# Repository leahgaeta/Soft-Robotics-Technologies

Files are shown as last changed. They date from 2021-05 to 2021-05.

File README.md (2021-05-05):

# Soft Robotic Technologies
This repo includes everything needed to build a capacitive sensing sock with a laminar jamming stiffening mechanism to correct and stabilize ankle movement, as well as videos created for my Soft Robotic Technologies course taught by [Professor Tommaso Ranzani](https://www.bu.edu/eng/profile/tommaso-ranzini-phd/) at Boston University (ME 568).

### A Capacitive-Sensing Sock with Laminar Jamming Stiffening to Correct & Stabilize Over-Plantar Flexion at the Ankle
**Materials for Fabrication & Testing:**
- [Capacitive-sensing sock](https://github.com/leahgaeta/Soft-Robotics-Technologies/raw/main/CapSenseSock.pdf)
  - [Mold .stl file](https://github.com/leahgaeta/Soft-Robotics-Technologies/blob/main/CapSenseMold.stl) - recommend preheating the build plate to improve adhesion and prevent thermal warping; also recommend print settings of 160 microns layer height, 40 mm/s print speed, 15% cubic infill.
  - [Mold drawing](https://github.com/leahgaeta/Soft-Robotics-Technologies/raw/main/CapSensorDrawing.pdf) - for overall dimensions if fabricating the mold without a 3D printer.
- [Laminar jamming mechanism](https://github.com/leahgaeta/Soft-Robotics-Technologies/raw/main/LJ_Materials.pdf)

**Procedure:**
- [Capacitive sensor fabrication](https://github.com/leahgaeta/Soft-Robotics-Technologies/raw/main/CapSensorFabrication.pdf)
- [Capacitive sensor with the sock]()
- [Laminar jamming structure]()
- [Arduino hook-up]()
- [Arduino code](https://github.com/leahgaeta/Soft-Robotics-Technologies/blob/main/ME568_Final_Project.ino)
- [Measuring ankle plantar flexion](https://github.com/leahgaeta/Soft-Robotics-Technologies/raw/main/AngleMeasure.pdf)
- [Validation of functionality]()

**Videos:**
- [Preliminary testing of the vacuum pump with the microcontroller in response to capacitance](https://www.youtube.com/watch?v=6RODMb19xsY&list=PLcbK43wpe5npEgS4IPYMW3b8mG1NXDAUV&index=7)
- [Example of prototype testing](https://www.youtube.com/watch?v=m9hGfniaSMc&list=PLcbK43wpe5npEgS4IPYMW3b8mG1NXDAUV&index=8)

### Other Explored Soft Robotic Technologies
- [SDM Finger Cable-Actuation](https://www.youtube.com/watch?v=M-p_GvDbpxU&list=PLcbK43wpe5npEgS4IPYMW3b8mG1NXDAUV&index=1)
- [Fluidic Actuators](https://www.youtube.com/watch?v=uoCWdHJRbhE&list=PLcbK43wpe5npEgS4IPYMW3b8mG1NXDAUV&index=2)
- [TPE Balloon Actuator](https://www.youtube.com/watch?v=CA4r7Kx_r18&list=PLcbK43wpe5npEgS4IPYMW3b8mG1NXDAUV&index=3)
- [Shape-Memory Alloy Actuator](https://www.youtube.com/watch?v=QtGa-lT5LOc&list=PLcbK43wpe5npEgS4IPYMW3b8mG1NXDAUV&index=4)
- [Soft Sensing](https://www.youtube.com/watch?v=x_DoucdEBAE&list=PLcbK43wpe5npEgS4IPYMW3b8mG1NXDAUV&index=5)
- [Granular & Laminar Jamming](https://www.youtube.com/watch?v=GqvPBZalNiA&list=PLcbK43wpe5npEgS4IPYMW3b8mG1NXDAUV&index=6)

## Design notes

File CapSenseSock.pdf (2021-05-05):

## Capacitive-Sensing Sock Materials

Leah T. Gaeta
Boston University, Dept. of Mechanical Engineering
- EcoFlex 00-30 Parts A & B (https://www.amazon.com/Smooth-Ecoflex-00-50-Platinum-Silicone/dp/B00GJ80HIC)
- 1.75 mm PLA for mold printing; (https://www.hatchbox3d.com/collections/pla) if no access to a 3D printer, then cardboard, hot glue, and packaging tape will suce for making the mold
- Mixing utensils for mixing Parts A and B together (https://www.amazon.com/dp/B08GCJ9KYH?aaxitk=fbd0d167cb8958185a16a57649ce70a7&hsa_cr_id=3728124250601)
- Xacto Knife (https://www.amazon.com/X-ACTO-2-Knife-Safety-Cap/dp/B000V1QV7O?hvadid=167119535166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)
- Conductive knit fabric (https://www.adafruit.com/product/1167)
- Ruler (https://www.amazon.com/Officemate-Classic-Stainless-Measurements-66612/dp/B00IXLPO8G?s=industrial) or measuring tape
- Sewing needle & thread (https://www.amazon.com/Supplies-Accessories-Portable-Traveller-Emergency/dp/B07FD297GK)
- Cotton sock, unisex size (https://www.amazon.com/gp/product/B08KYCYWJ6/ref=ppx_yo_dt_b_asin_title_o03_s00?ie=UTF8&psc=1)
- Extra fabric (https://www.amazon.com/Canvas-Drop-Cloth-Size-Cotton/dp/B07TBHJJ62)
- Alligator clips (https://www.amazon.com/gp/product/B06XX25HFX/ref=ppx_yo_dt_b_asin_title_o01_s01?ie=UTF8&psc=1)
- Goniometer (https://www.amazon.com/gp/product/B07SJ54W63/ref=ppx_yo_dt_b_asin_title_o03_s00?ie=UTF8&psc=1)
- Arduino Uno, jumper wires, and USB connection to a computer (https://store.arduino.cc/usa/arduino-starter-kit)

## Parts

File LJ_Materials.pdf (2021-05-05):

## Laminar Jamming Materials

Leah T. Gaeta
Boston University, Dept. of Mechanical Engineering
- Printer paper (https://www.amazon.com/gp/product/B00006L38Q/ref=ppx_yo_dt_b_asin_title_o01_s01?ie=UTF8&psc=1)
- Scissors & ruler
- Stretchlon TPE (https://www.fibreglast.com/product/stretchlon-200-bagging-film-1678/Vacuum_Bagging_Films_Peel_Ply_Tapes)
- Iron & ironing board (https://www.amazon.com/dp/B082JG1SR6?aaxitk=7f2c8ed0a6aad44603be81251b5097b4&hsa_cr_id=6329978520001)
- Aluminum foil (https://www.amazon.com/Reynolds-Wrap-Aluminum-Foil-Square/dp/B00UNT0Y2M?rdc=1)
- 3/16 in. tubing (https://www.amazon.com/Silicon-CellarBrew-Silicone-Brewing-Winemaking/dp/B07TH8H1QP)
- Miniature pump (https://www.amazon.com/NW-5V-6VDC-Miniature-Vacuum-100KPa/dp/B078H8V563)
- Transistors (https://www.amazon.com/Pieces-TIP120-Power-Darlington-Transistors/dp/B00NAY1IBS) & diodes (diodes can be found at the Arduino link)
- Locktite Adhesive (https://www.amazon.com/Loctite-Plastic-Adhesive-1-Ounce-1360694/dp/B001F7E9VI)
- Extra fabric (https://www.amazon.com/Canvas-Drop-Cloth-Size-Cotton/dp/B07TBHJJ62)
- Arduino Uno, jumper wires, and USB connection to a computer (https://store.arduino.cc/usa/arduino-starter-kit)

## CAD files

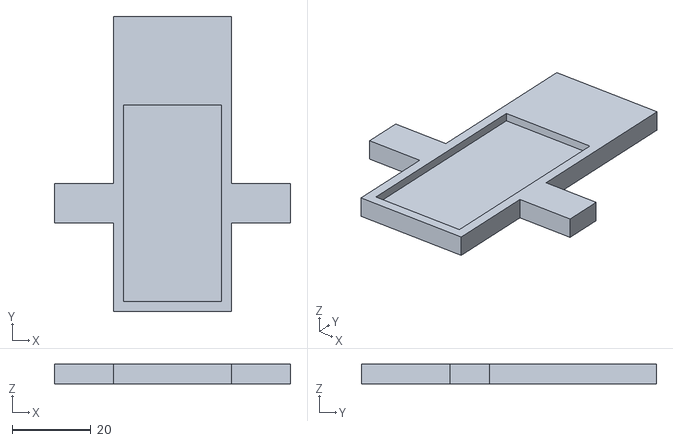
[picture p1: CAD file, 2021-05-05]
CapSenseMold.stl
60.0 x 75.0 x 5.00

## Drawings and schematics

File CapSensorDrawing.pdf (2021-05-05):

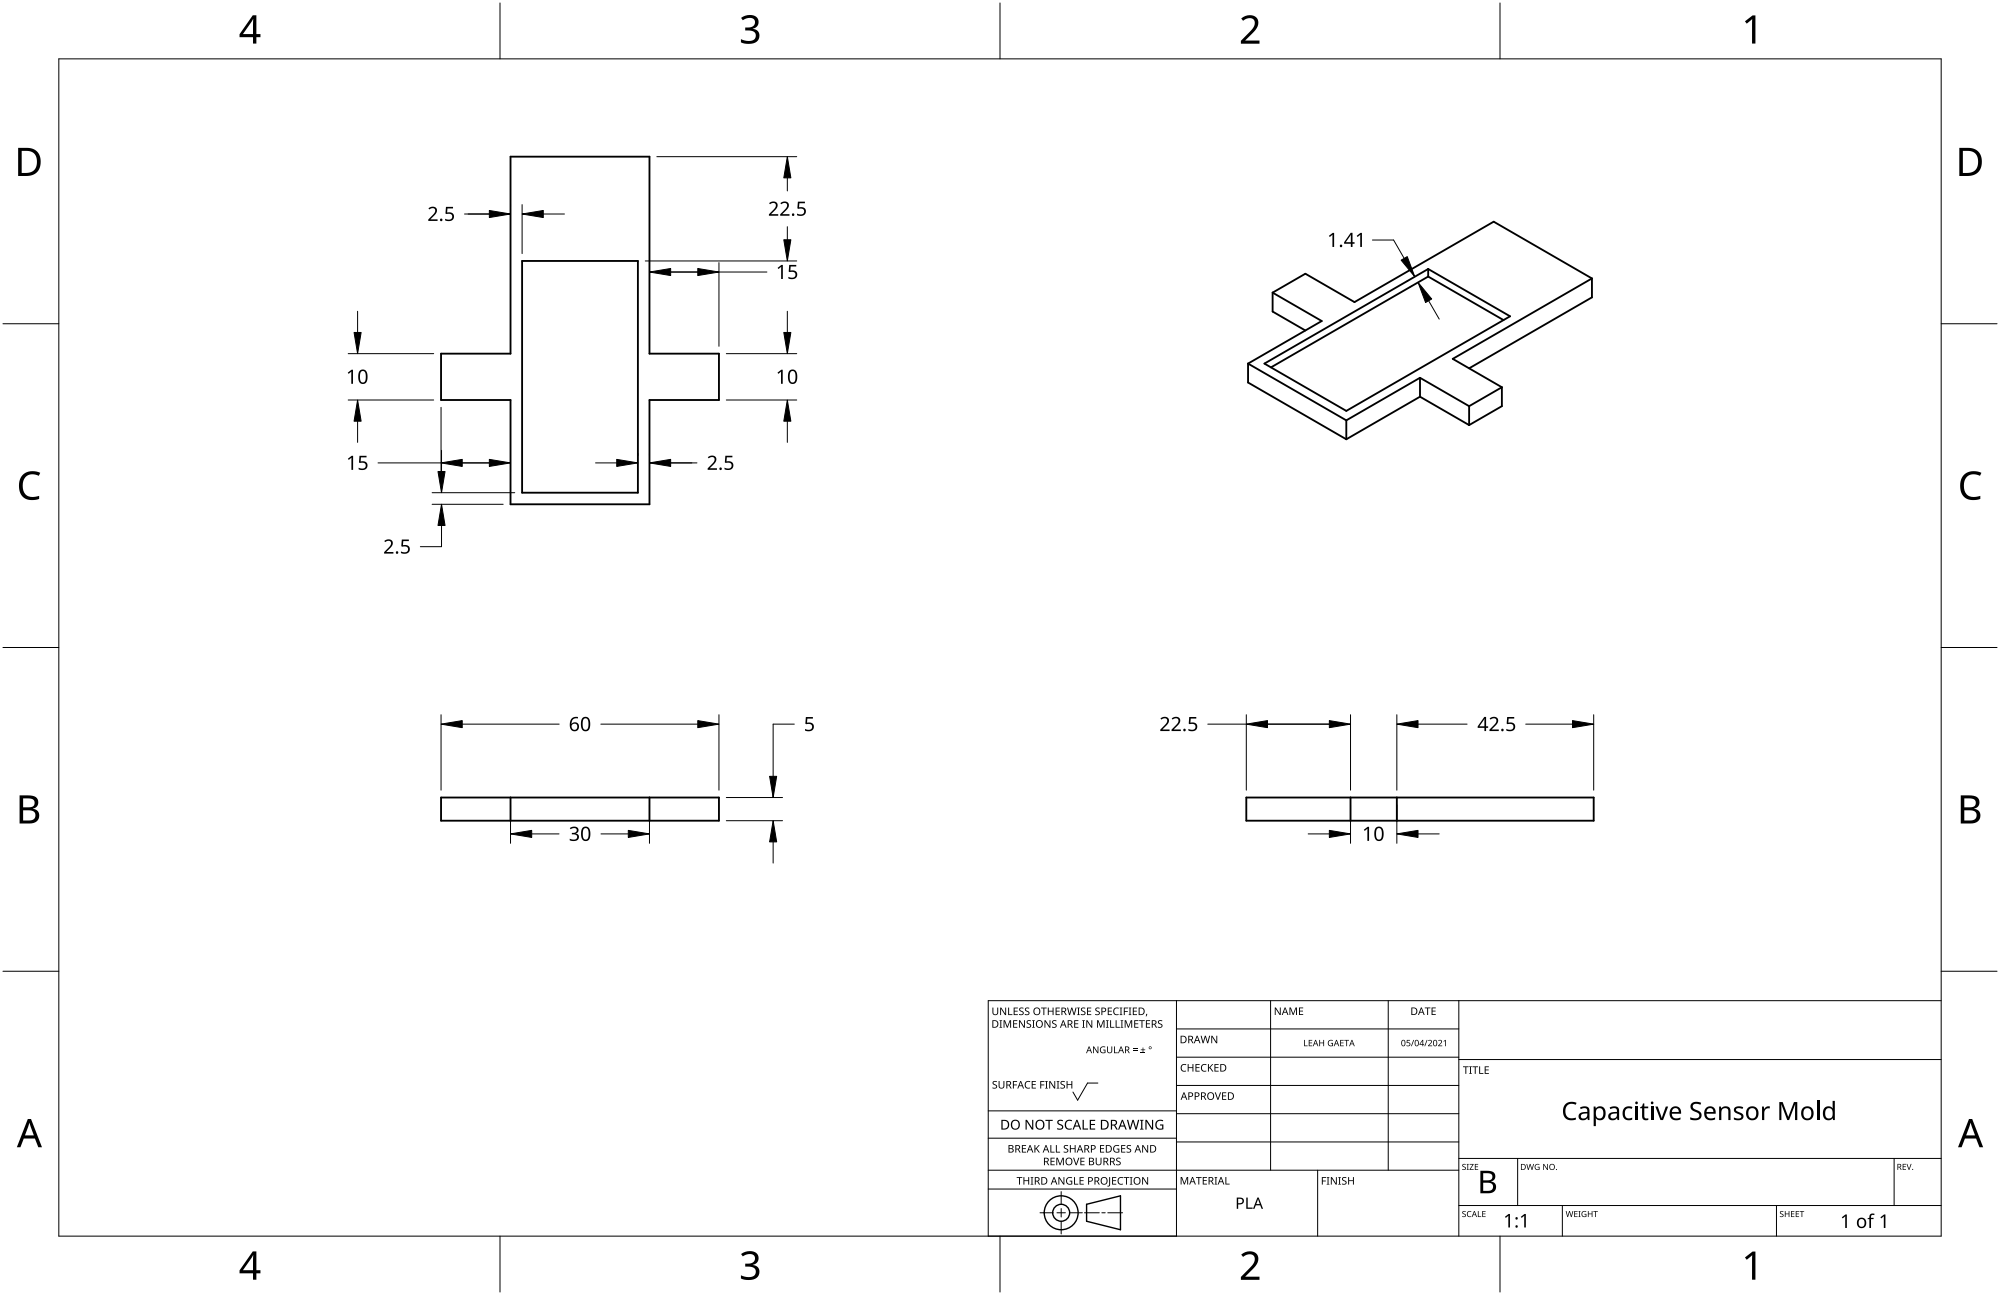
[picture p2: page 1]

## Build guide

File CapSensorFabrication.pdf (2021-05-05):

## Capacitive Sensor Fabrication Procedure

Leah T. Gaeta
Boston University, Dept. of Mechanical Engineering
1. Mix thoroughly equal volumes of Parts A & B of EcoFlex 00-30 (approximately 20 ml total).
2. Carefully pour the silicone mixture into the mold, avoiding bubbles as much as possible. Level out with a wooden stirrer. Let cure at room temperature for four hours.
3. Identify the stretchable axis of the conductive fabric. This must be the direction that the fabric is tensilely strained in. Cut two pieces of fabric according the dimensions of the inner mold and include a single ”flap” that measures 10 mm x 15 mm (see the drawing on the GitHub). These flaps will be where the alligator clips connect. Also cut two square 20 mm x 20 mm pieces of regular fabric.
4. Carefully lay one of the cut pieces of the conductive fabric onto the cured mold. Laminate the fabric with a thin layer of well-mixed EcoFlex 00-30 to adhere it to the mold. Be sure to not get any silicone elastomer on the flaps. In addition, place one small square of regular fabric along the flat portion of the mold, overlapping with some of the cured silicone but making sure not to touch the conductive fabric.
5. After a couple of hours of curing, carefully remove the sensor with the now-adhered fabric from the mold using the Xacto knife. Flip over, lay the other piece of cut conductive fabric on this side so that it is aligned with the other piece of fabric on the opposite side, and laminate as before, taking care to not get any silicone on the flap. Adhere the square piece of fabric as before also.
6. After curing for a couple of hours, carefully removed the sensor from the mold again, and trim as necessary, making sure to keep a consistent border of silicone around the conductive fabric.

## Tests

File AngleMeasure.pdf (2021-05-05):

## Measuring Ankle Angles with a Goniometer

Leah T. Gaeta
Boston University, Dept. of Mechanical Engineering
1. Align the center of the goniometer with the lateral aspect of the lateral malleolus.
2. Bring the ankle to a neutral 90 degrees.
3. Align one end of the goniometer with the approximate middle of the shank (lower leg). This will be the stationary part.
4. Align the other end of the goniometer with the 5th metatarsal. This is the moving end.
5. Measure various angles of plantar flexion and approximate capacitance values from the Arduino Serial Monitor. The angles are reported as relative to the neutral 90 degree ankle position. For instance, 10 degrees of dorsiflexion would be -10 degrees of plantar flexion.

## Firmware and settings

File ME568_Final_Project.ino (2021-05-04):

/*****
  ME 568 Final Project Prototype: Capacitive sensor sock with laminar jamming stiffening mechanism.
  Leah T. Gaeta
  2021 - 04 - 25
*****/

// Libraries
#include <Capacitor.h>
#include <CapacitorLite.h>
#include <MeanFilterLib.h>

MeanFilter<float> meanFilter(10); // Moving average with window = 10

int CAP_TERMINAL_A = 7;
int CAP_TERMINAL_B = A2; 
//int solenoidPin = 9; // Solenoid output pin
int pumpPin = 2;

CapacitorLite cap1(CAP_TERMINAL_A, CAP_TERMINAL_B);

float rawCapacitance;
float meanCapacitance; 

void setup() {
  //pinMode(solenoidPin, OUTPUT); // Sets solenoid pin as output here
  pinMode(pumpPin, OUTPUT);
  Serial.begin(9600); // Serial transmission rate
}

void loop() {
  rawCapacitance = cap1.Measure(); 
  meanCapacitance = meanFilter.AddValue(rawCapacitance); // calculates moving average, removes *some* noise
  Serial.println(meanCapacitance); 
  
  // Test for threshold capacitance to activate LJ stiffening
  if (meanCapacitance > 1100){
    //digitalWrite(solenoidPin, HIGH); // Solenoid on
    //digitalWrite(solenoidPin, HIGH);      //Switch Solenoid ON
    digitalWrite(pumpPin, HIGH);
    //delay(2000);  //Wait 2 Seconds
  }
  else{
    //digitalWrite(solenoidPin, LOW);       //Switch Solenoid OFF
    digitalWrite(pumpPin, LOW);
    //delay(2000);                          //Wait 2 Seconds
  }
}
